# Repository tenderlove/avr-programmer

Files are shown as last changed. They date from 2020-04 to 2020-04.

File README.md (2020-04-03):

# My AVR Programmer

I've been messing around with an atmega328p and I kept finding myself building the same circuit on every breadboard.
In order to save time and breadboard space I decided to make an atmega328p breakout board.

This board works well with the [Sparkfun Pocket AVR programmer](https://www.sparkfun.com/products/9825).

Here is a photo:

photo of dev board

## Parts list

* 1 [24 pin ZIF socket](https://www.aliexpress.com/item/32655076081.html)
* 1 [LD1117V33 voltage regulator](https://www.aliexpress.com/item/32892526691.html)
* 1 10uf capacitor
* 1 100nf capacitor
* 1 2N7000 MOSFET
* 1 [Mini USB B connector](https://www.digikey.com/product-detail/en/edac-inc/690-005-299-043/151-1206-1-ND/4312192)
* 1 [6 pin box header](https://www.digikey.com/product-detail/en/w-rth-elektronik/61200621621/732-5394-ND/4846913)
* 2 [15 pin 2.54mm headers](https://www.digikey.com/product-detail/en/sullins-connector-solutions/PPTC151LFBN-RC/S7013-ND/810153)

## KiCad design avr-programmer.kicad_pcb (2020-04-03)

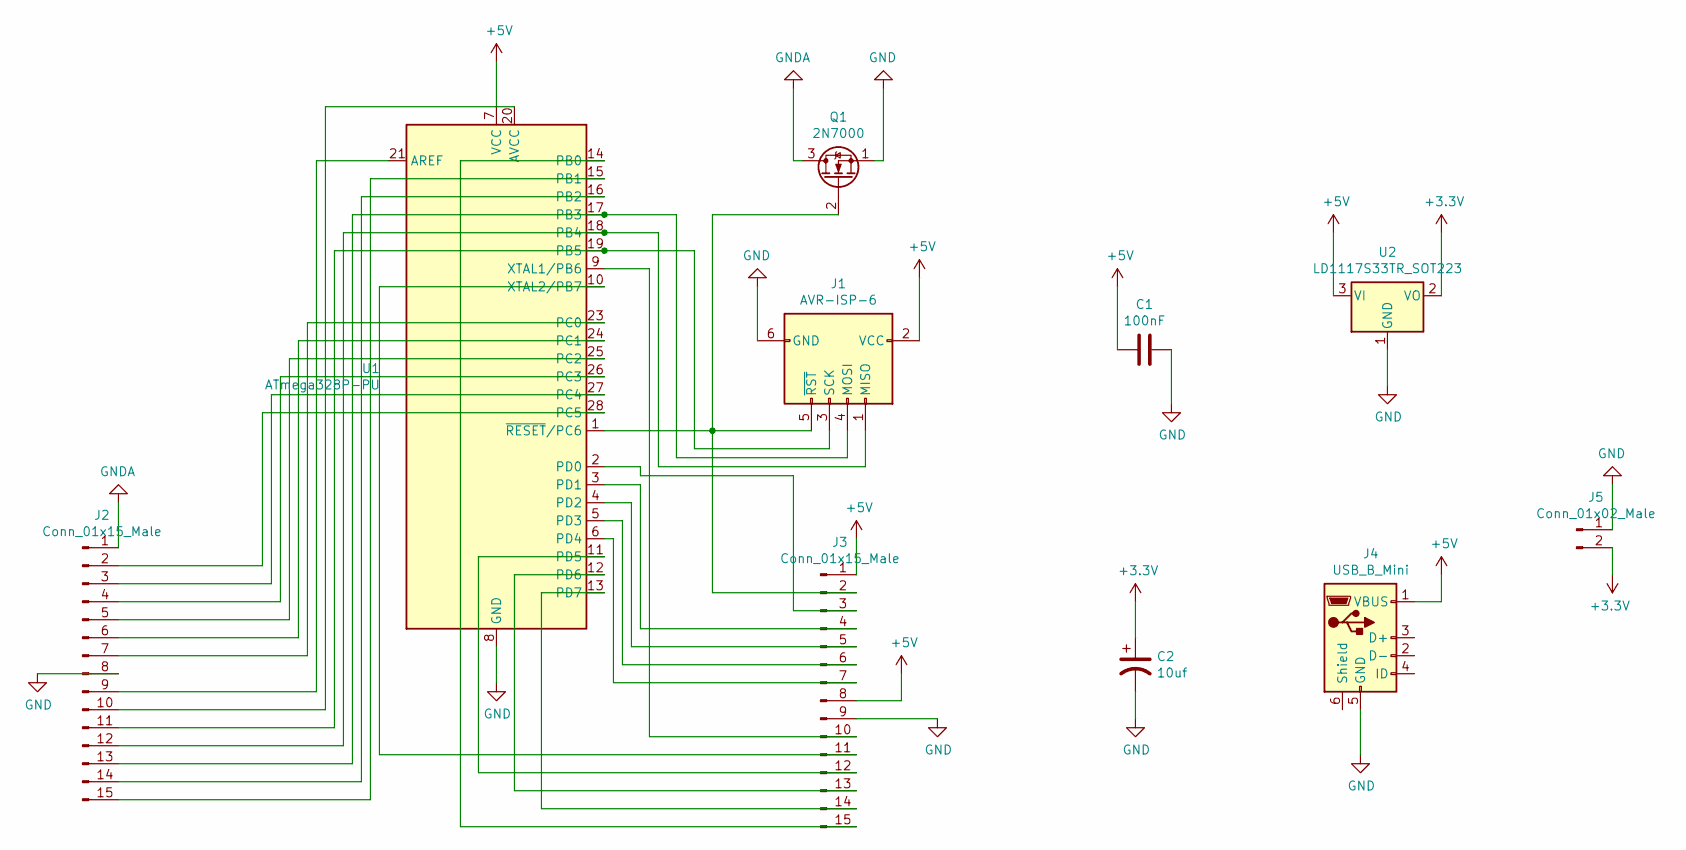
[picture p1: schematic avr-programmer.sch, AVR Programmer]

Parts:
C1: 100nF; C_Disc_D4.7mm_W2.5mm_P5.00mm
C2: 10uf; CP_Radial_D5.0mm_P2.00mm
J1: AVR-ISP-6; IDC-Header_2x03_P2.54mm_Vertical
J2, J3: Conn_01x15_Male; PinHeader_1x15_P2.54mm_Vertical
J4: USB_B_Mini; USB_Mini-B_Lumberg_2486_01_Horizontal
J5: Conn_01x02_Male; PinHeader_1x02_P2.54mm_Vertical
Q1: 2N7000; TO-92_Inline
U1: ATmega328P-PU; DIP-28_W7.62mm_ZIF
U2: LD1117S33TR_SOT223; TO-220-3_Horizontal_TabDown

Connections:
+3V3: C2.1, J5.2, U2.2 (VO)
+5V: C1.2, J1.2 (VCC), J3.1, J3.8, J4.1 (VBUS), U1.7 (VCC), U2.3 (VI)
GND: C1.1, C2.2, J1.6 (GND), J2.8, J3.9, J4.5 (GND), J5.1, Q1.1 (S), U1.8 (GND), U1.22 (GND), U2.1 (GND)
GNDA: J2.1, Q1.3 (D)
unnamed: J1.1 (MISO), J2.12, U1.18 (PB4)
unnamed: J1.3 (SCK), J2.11, U1.19 (PB5)
unnamed: J1.4 (MOSI), J2.13, U1.17 (PB3)
unnamed: J1.5 (~RST), J3.2, Q1.2 (G), U1.1 (~RESET~/PC6)
unnamed: J2.2, U1.28 (PC5)
unnamed: J2.3, U1.27 (PC4)
unnamed: J2.4, U1.26 (PC3)
unnamed: J2.5, U1.25 (PC2)
unnamed: J2.6, U1.24 (PC1)
unnamed: J2.7, U1.23 (PC0)
unnamed: J2.9, U1.21 (AREF)
unnamed: J2.10, U1.20 (AVCC)
unnamed: J2.14, U1.16 (PB2)
unnamed: J2.15, U1.15 (PB1)
unnamed: J3.3, U1.2 (PD0)
unnamed: J3.4, U1.3 (PD1)
unnamed: J3.5, U1.4 (PD2)
unnamed: J3.6, U1.5 (PD3)
unnamed: J3.7, U1.6 (PD4)
unnamed: J3.10, U1.9 (XTAL1/PB6)
unnamed: J3.11, U1.10 (XTAL2/PB7)
unnamed: J3.12, U1.11 (PD5)
unnamed: J3.13, U1.12 (PD6)
unnamed: J3.14, U1.13 (PD7)
unnamed: J3.15, U1.14 (PB0)

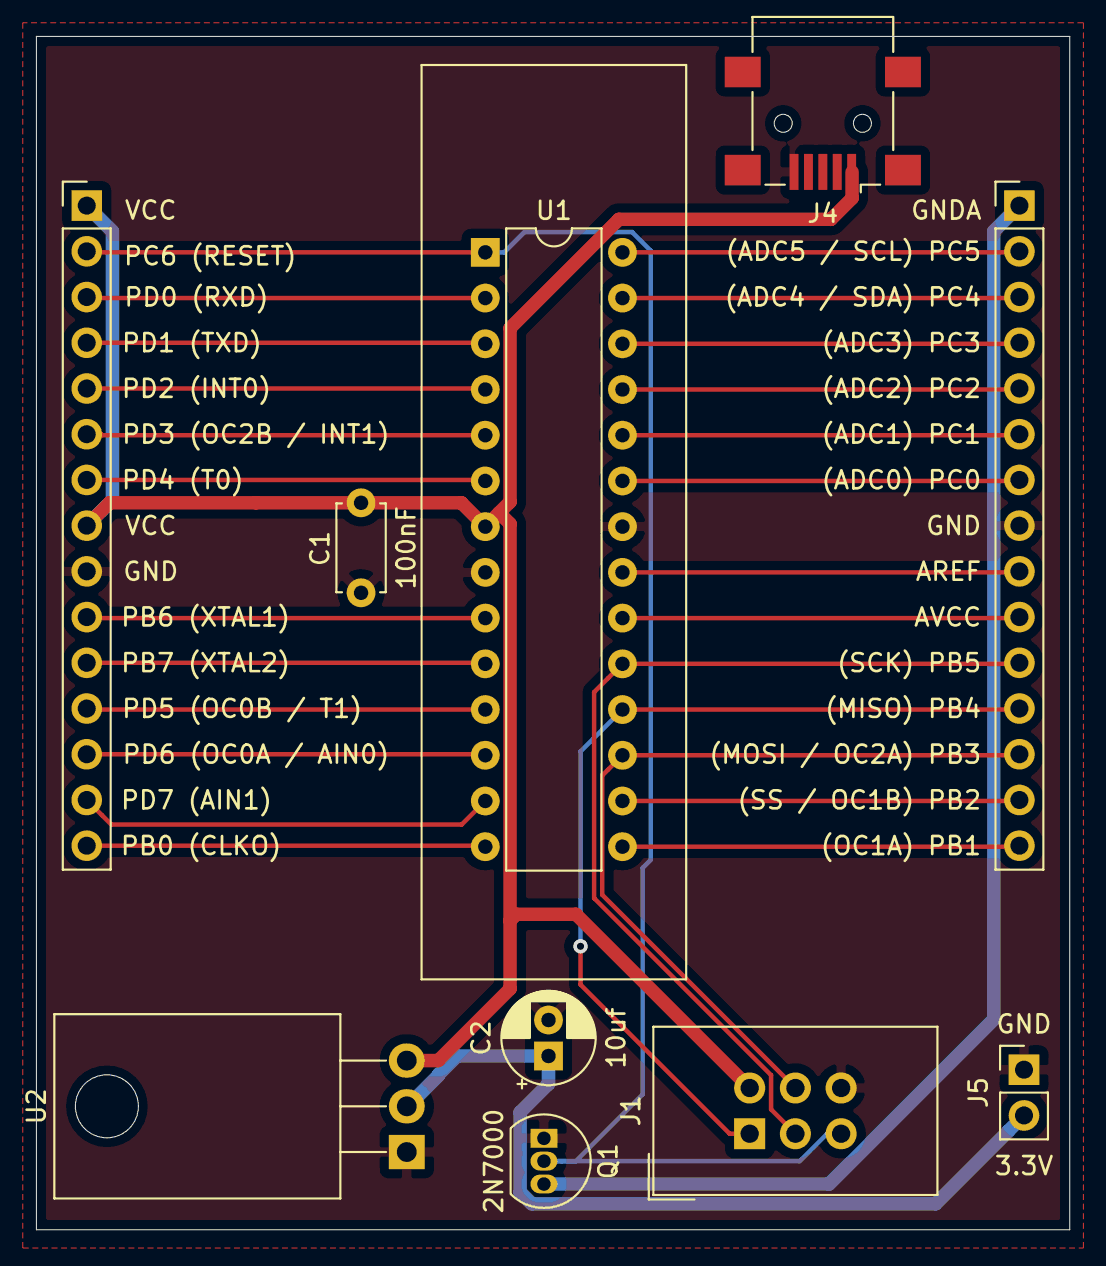
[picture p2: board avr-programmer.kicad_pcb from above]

Board: 2 copper layers, 57.4 x 66.3 mm, 10 parts (0 on the bottom side), 29 nets.

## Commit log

2020-04-03 udating everything I guess!
    [avr-programmer.kicad_pcb, avr-programmer.sch]
2020-04-03 fix gerbers
    [avr-programmer.kicad_pcb]
